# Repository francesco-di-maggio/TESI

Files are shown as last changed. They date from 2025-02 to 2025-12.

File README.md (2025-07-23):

# TESI — TANGIBLE EMBODIED SOUND INTERACTION

<p align="left">
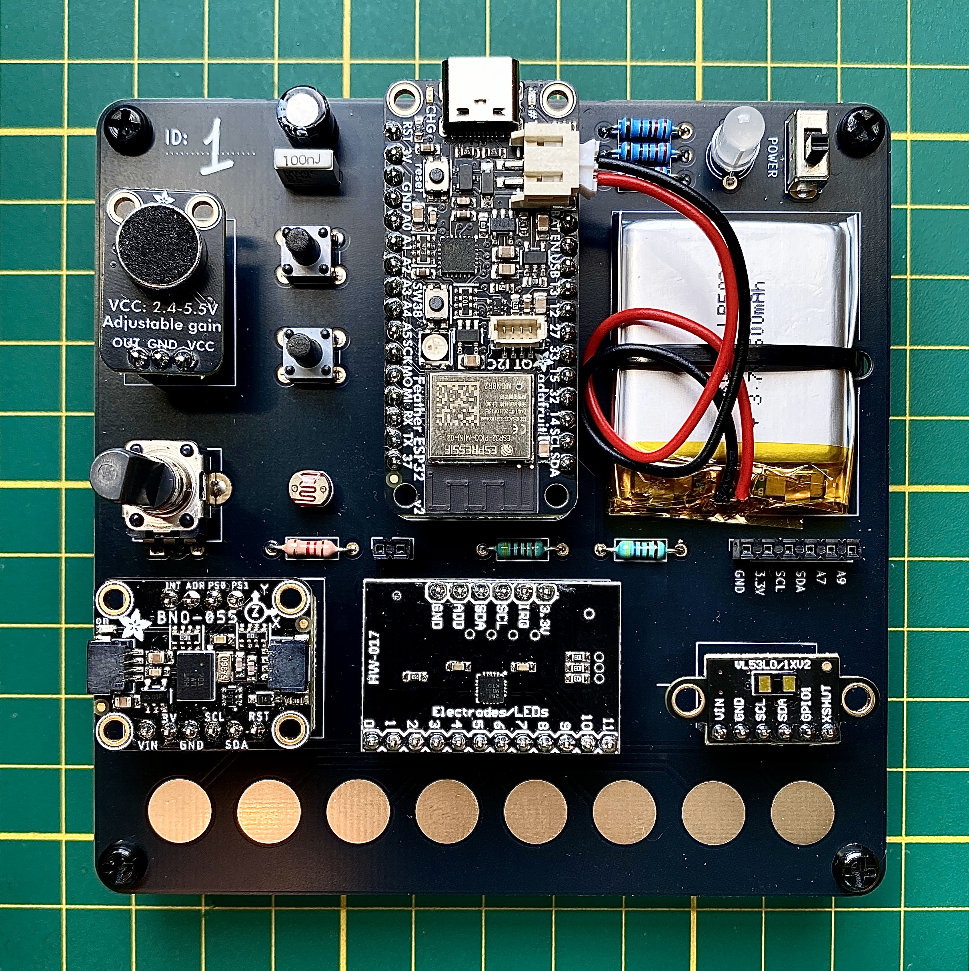
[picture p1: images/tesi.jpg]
TESI
  
</p>

## About
TESI (Tangible Embodied Sound Interaction) is an open-source prototype designed as a sound-centered Tangible User Interface (TUI) for networked, interactive music systems. It enables real-time sensor-based interaction for embodied sound exploration.

TESI is a modular, wireless, and networked interface, leveraging machine learning, decentralized communication, and digital musical instrument (DMI) design. 

### Features
* Wireless and networked using [Adafruit ESP32 Feather V2 - 8MB Flash + 2 MB PSRAM - STEMMA QT](https://www.adafruit.com/product/5400) and [OOCSI](https://oocsi.id.tue.nl/).
* Multi-sensor data collection:
  * Motion (IMU) – BNO055
  * Light – Light-Dependent Resistor (LDR)
  * Distance – Time-of-flight (ToF)
  * Capacitive Touch – MPR121
  * Audio – MAX4466
  * Potentiometer
* Integration with [Max](https://cycling74.com/products/max) via TCP [(Sadam Library)](https://cycling74.com/packages/sadam-library) to process and map data to [Ableton Live](https://www.ableton.com/en/live/).
* Machine learning-based mapping using:
  * FluCoMa
* Custom PCB design (open-source schematics included).

### Repository Contents
* ableton/ – Example Ableton Live set for sound interaction.
* arduino/ – ESP32 firmware for sensor data collection and communication.
* kicad/ – Open-source KiCad schematics and PCB layouts.
* max/ – Max/MSP patches for data processing, mapping, and control.
* oocsi/ - OOCSI local server.

## Setup & Installation
1. Flash the ESP32 with Arduino
  * Install Arduino IDE and ESP32 board support.
  * Upload the firmware in /arduino to ESP32 Feather V2.
2. Set up OOCSI Communication
  * Ensure an OOCSI Server is running.
  * Configure the ESP32 and Max/MSP to connect.
3. Run Max/MSP and Ableton Live
  * Open the Max patches (/max) for data reception and processing.
  * Load the Ableton Live set to explore interactive sound control.

### Dependencies
To work in Max, TESI requires external libraries including:
* (modulo)[https://cycling74.com/packages/modulo]
* (oocsi-max)[https://github.com/francesco-di-maggio/oocsi-max]
* (odot)[https://cycling74.com/packages/odot]
* (Sadam Library)[https://cycling74.com/packages/sadam-library]
* (FluCoMa)[https://www.flucoma.org/]

### Networked Interaction & Distributed Control
TESI operates as part of a system of interconnected objects, using OOCSI for wireless communication between multiple devices. This enables:

* Real-time multi-agent interaction
* Collaborative sound generation
* Adaptive, sensor-driven soundscapes

### Research & Development
TESI is part of my ongoing PhD research at TU Eindhoven, focusing on:

* Tangible and Embodied Interaction
* Modular and Decentralized Ecologies of Smart Objects
* Sound Interaction in TEI and IoT
* Sustainable Interaction Design

## Publications
* Francesco Di Maggio, Bart Hengeveld, and Mathias Funk. 2025. [Making Sense of Decentralized TUIs: A Modular Sound-Centric Approach](https://dl.acm.org/doi/10.1145/3689050.3708332). Proceedings of the Nineteenth International Conference on Tangible, Embedded, and Embodied Interaction. Association for Computing Machinery, New York, NY, USA, Article 136, 1–3. https://doi.org/10.1145/3689050.3708332

### Next Presentation
TESI's first prototype will be presented at (TEI'25)[https://tei.acm.org/2025/] (Tangible, Embedded, and Embodied Interaction) in Bordeaux, France, during a Studio session exploring sustainable, modular, and embodied interaction in sound design., ["Making Sense of Decentralized TUIs: A Modular Sound-Centric Approach"](https://sites.google.com/view/decentralized-sound-tuis/home).

### Contribute & Collaborate
TESI is open-source, and contributions are welcome. You can contribute by:

* Expanding hardware (sensor integration, PCB improvements)
* Enhancing software (Max patches, mappings, sound engines)
* Exploring new applications (live performance, installations, research)
Fork this repository, submit pull requests, or start a discussion in the issues section.

## Credits
### PCB Layout & Schematics
Designed and assembled at TU/e in the [d.search lab](https://research.tue.nl/en/equipments/dsearch-lab) with [Katrien van Riet](https://www.vectorious.nl/) and Geert van den Boomen.

### OOCSI to Plugdata/Max Implementation
Designed at TU/e with [Mathias Funk](https://mathias-funk.com/).

## License
TESI is released under the MIT License, making it free to use, modify, and share.

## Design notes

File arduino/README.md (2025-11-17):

# Arduino Firmware

## Description
ESP32 Feather V2 firmware for multi-sensor data collection and wireless transmission. Reads sensor data, processes it locally, and transmits via OSC, Serial, and OOCSI protocols.

## Hardware Platform
- **MCU**: ESP32 Feather V2
- **Communication**: Wi-Fi 802.11b/g/n
- **Power**: Battery monitoring with voltage divider
- **I/O**: Multiple ADC channels, I2C, GPIO

## Sensor Configuration
The firmware supports the following sensors:

| Sensor | Type | Interface | Purpose |
|---|---|---|---|
| BNO055 | IMU | I2C | Quaternion orientation tracking |
| VL53L1X | ToF Distance | I2C | Proximity detection |
| MPR121 | Capacitive Touch | I2C | 12-channel touch sensing |
| MAX4466 | Microphone | ADC | Environmental sound level |
| LDR | Light Sensor | ADC | Ambient light detection |
| Potentiometer | Analog | ADC | Manual control input |
| Push Button | Digital | GPIO | Discrete input |
| Battery | Voltage | ADC | Power monitoring |

## Project Structure
```
tesi/
├── tesi.ino              # Main Arduino sketch
└── src/
    ├── config.h           # Hardware pin definitions and settings
    ├── config.cpp         # Sensor enable/disable configuration
    ├── secrets.h          # Network credentials (create from template)
    ├── secrets.template.h # Template for network configuration
    ├── sensors.h          # Sensor initialization declarations
    ├── sensors.cpp        # Central sensor management
    ├── stream.h           # Data streaming interface
    ├── stream.cpp         # Main sensor reading loop
    ├── network.h          # Network connectivity interface
    ├── network.cpp        # Wi-Fi and OOCSI implementation
    ├── osc.h              # OSC protocol handling
    ├── osc.cpp            # OSC message formatting and transmission
    ├── ping.h             # Network connectivity monitoring
    ├── ping.cpp           # Ping functionality implementation
    ├── utilities.h        # Shared utility functions
    ├── utilities.cpp      # Serial and OOCSI output functions
    └── [sensor].h/.cpp    # Individual sensor implementations
```

## Configuration
1. **Network Setup**: Copy `secrets.template.h` to `secrets.h` and configure network credentials
2. **Device Identity**: Edit `DEVICE_INDEX` in `config.cpp` to match your physical board number (1, 2, 3, etc.)
3. **OOCSI Protocol**: Uncomment `#define USE_OOCSI` in `config.h` to enable OOCSI communication
4. **Sensor Selection**: Edit `config.cpp` to enable/disable sensors and communication protocols:

### Sensor Configuration Options
Each sensor in `config.cpp` can be configured with the following parameters:
```cpp
SensorConfig SENSOR_NAME = {enabled, osc, serial, oocsi, interval, lastUpdate};
```

| Parameter | Type | Description |
|---|---|---|
| `enabled` | 1/0 | Sensor initialization and data collection |
| `osc` | 1/0 | OSC/UDP message transmission |
| `serial` | 1/0 | Serial port output for debugging |
| `oocsi` | 1/0 | OOCSI protocol transmission |
| `interval` | ms | Update frequency in milliseconds |

### Available Sensors
| Sensor | Variable | Default Interval | Purpose |
|---|---|---|---|
| Battery | `BATTERY` | 5000ms | Power monitoring |
| Light Sensor | `LDR` | 20ms | Ambient light detection |
| Microphone | `MIC` | 30ms | Environmental sound level |
| Potentiometer | `POT` | 10ms | Manual control input |
| Distance | `DISTANCE` | 20ms | VL53L1X proximity detection |
| Quaternion | `QUAT` | 30ms | BNO055 orientation tracking |
| Push Button | `PUSH` | 5ms | Discrete input |
| Capacitive Touch | `CAP` | 5ms | MPR121 touch sensing |
| Heartbeat Ping | `PING` | 1000ms | Device alive status monitoring |

5. **Update Rates**: Adjust sensor polling intervals in individual sensor configurations

### Important Configuration Notes
- **Device Index**: Each board must have a unique `DEVICE_INDEX` value in `config.cpp` for proper identification
- **OOCSI Enable**: Uncomment `// #define USE_OOCSI` in `config.h` to activate OOCSI protocol functionality

## Network Protocols
- **OSC**: Open Sound Control over UDP for real-time applications
- **Serial**: Direct UART output for debugging and local monitoring  
- **OOCSI**: Distributed messaging protocol for multi-device coordination

## Compilation Requirements
- **Arduino IDE**: Version 2.0 or later
- **ESP32 Board Package**: Version 3.1.2 (Espressif Systems ESP32 boards)
- **Libraries**:
  - Adafruit BNO055
  - Adafruit VL53L1X
  - Adafruit MPR121 (version 1.1.3)
  - WiFi (ESP32 core)
  - WiFiUdp (ESP32 core)
  - OOCSI

## Sensor Architecture
Each sensor follows a consistent three-function pattern:
- `init[Sensor]()`: Hardware initialization and configuration
- `read[Sensor]()`: Data acquisition and local processing
- `send[Sensor]()`: Conditional transmission based on change thresholds

## Data Processing
- **Filtering**: Exponential moving average (EMA) and noise reduction
- **Thresholding**: Change detection to minimize redundant transmissions
- **Scaling**: Sensor-specific calibration and range mapping

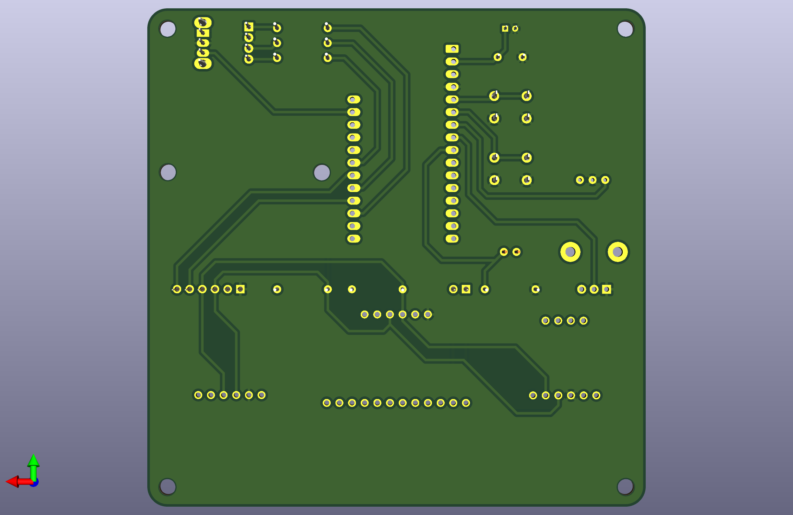
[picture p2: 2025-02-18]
kicad/tesi/tesi-pictures/tesi-pcb-b.png

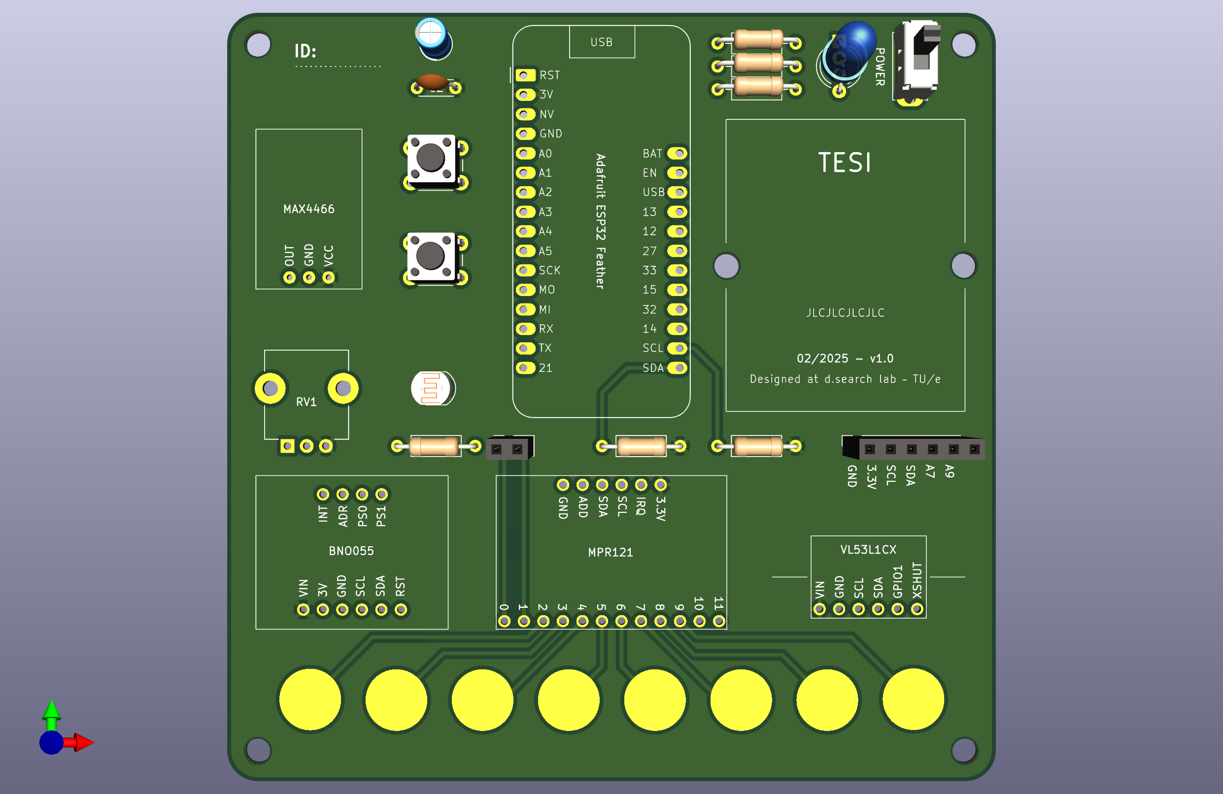
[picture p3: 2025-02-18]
kicad/tesi/tesi-pictures/tesi-pcb-a.png

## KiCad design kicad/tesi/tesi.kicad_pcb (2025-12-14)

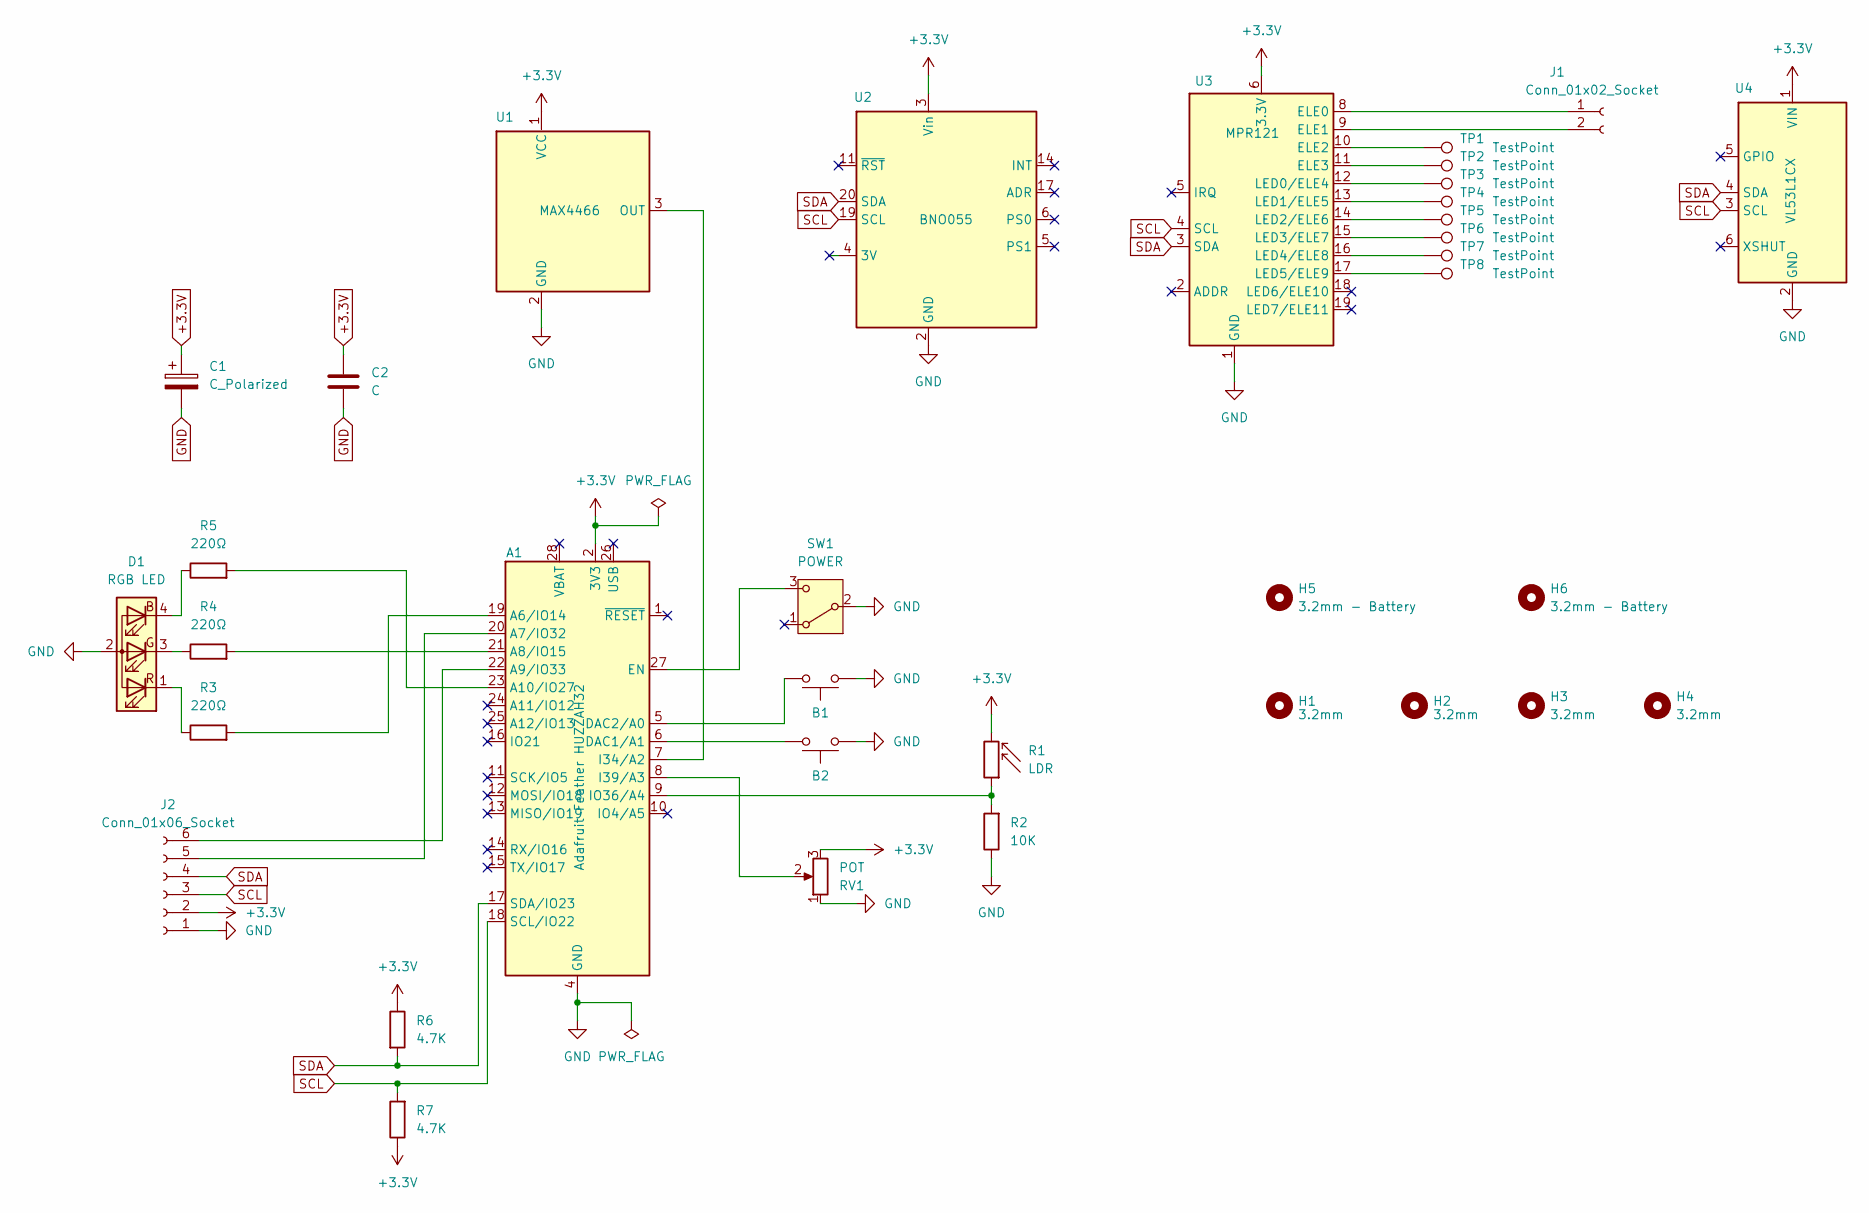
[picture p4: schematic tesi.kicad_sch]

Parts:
A1: Adafruit Feather HUZZAH32; Adafruit ESP32 Feather
B1, B2: SW_PUSH_6mm
C1: C_Polarized; CP_Radial_D4.0mm_P2.00mm
C2: C; C_Disc_D4.3mm_W1.9mm_P5.00mm
D1: RGB LED; LED_D5.0mm-4_RGB_Wide_Pins
H1, H2, H3, H4: 3.2mm; MountingHole_3.2mm_M3
H5, H6: 3.2mm - Battery; MountingHole_3.2mm_M3
J1: Conn_01x02_Socket; PinSocket_1x02_P2.54mm_Vertical
J2: Conn_01x06_Socket; PinSocket_1x06_P2.54mm_Vertical
R1: LDR; R_LDR_4.9x4.2mm_P2.54mm_Vertical
R2: 10K; R_Axial_DIN0207_L6.3mm_D2.5mm_P10.16mm_Horizontal
R3, R4, R5: 220Ω; R_Axial_DIN0207_L6.3mm_D2.5mm_P10.16mm_Horizontal
R6, R7: 4.7K; R_Axial_DIN0207_L6.3mm_D2.5mm_P10.16mm_Horizontal
RV1: POT; Potentiometer_TT_P0915N
SW1: POWER; Switch
TP1, TP2, TP3, TP4, TP5, TP6, TP7, TP8: TestPoint; TouchPad - 4.0mm
U1: MAX4466
U2: BNO055
U3: MPR121
U4: VL53L1CX; VL53L1X

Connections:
+3.3V: A1.2 (3V3), C1.1, C2.1, J2.2, R1.2, R6.1, R7.1, RV1.3, U1.1 (VCC), U2.3 (Vin), U3.6 (3.3V), U4.1 (VIN)
GND: A1.4 (GND), B1.1, B2.1, C1.2, C2.2, D1.2 (A), J2.1, R2.1, RV1.1, SW1.2 (B), U1.2 (GND), U2.2 (GND), U3.1 (GND), U4.2 (GND)
unnamed: A1.19 (A6/IO14), R3.2
unnamed: A1.20 (A7/IO32), J2.5
unnamed: A1.21 (A8/IO15), R4.2
unnamed: A1.22 (A9/IO33), J2.6
unnamed: A1.23 (A10/IO27), R5.2
unnamed: A1.6 (DAC1/A1), B2.2
unnamed: A1.5 (DAC2/A0), B1.2
unnamed: A1.27 (EN), SW1.3 (C)
unnamed: A1.7 (I34/A2), U1.3 (OUT)
unnamed: A1.8 (I39/A3), RV1.2
unnamed: A1.9 (IO36/A4), R1.1, R2.2
unnamed: D1.4 (BK), R5.1
unnamed: D1.3 (GK), R4.1
unnamed: D1.1 (RK), R3.1
unnamed: J1.1, U3.8 (ELE0)
unnamed: J1.2, U3.9 (ELE1)
unnamed: TP1.1, U3.10 (ELE2)
unnamed: TP2.1, U3.11 (ELE3)
unnamed: TP3.1, U3.12 (LED0/ELE4)
unnamed: TP4.1, U3.13 (LED1/ELE5)
unnamed: TP5.1, U3.14 (LED2/ELE6)
unnamed: TP6.1, U3.15 (LED3/ELE7)
unnamed: TP7.1, U3.16 (LED4/ELE8)
unnamed: TP8.1, U3.17 (LED5/ELE9)
SCL: A1.18 (SCL/IO22), J2.3, R7.2, U2.19 (SCL), U3.4 (SCL), U4.3 (SCL)
SDA: A1.17 (SDA/IO23), J2.4, R6.2, U2.20 (SDA), U3.3 (SDA), U4.4 (SDA)

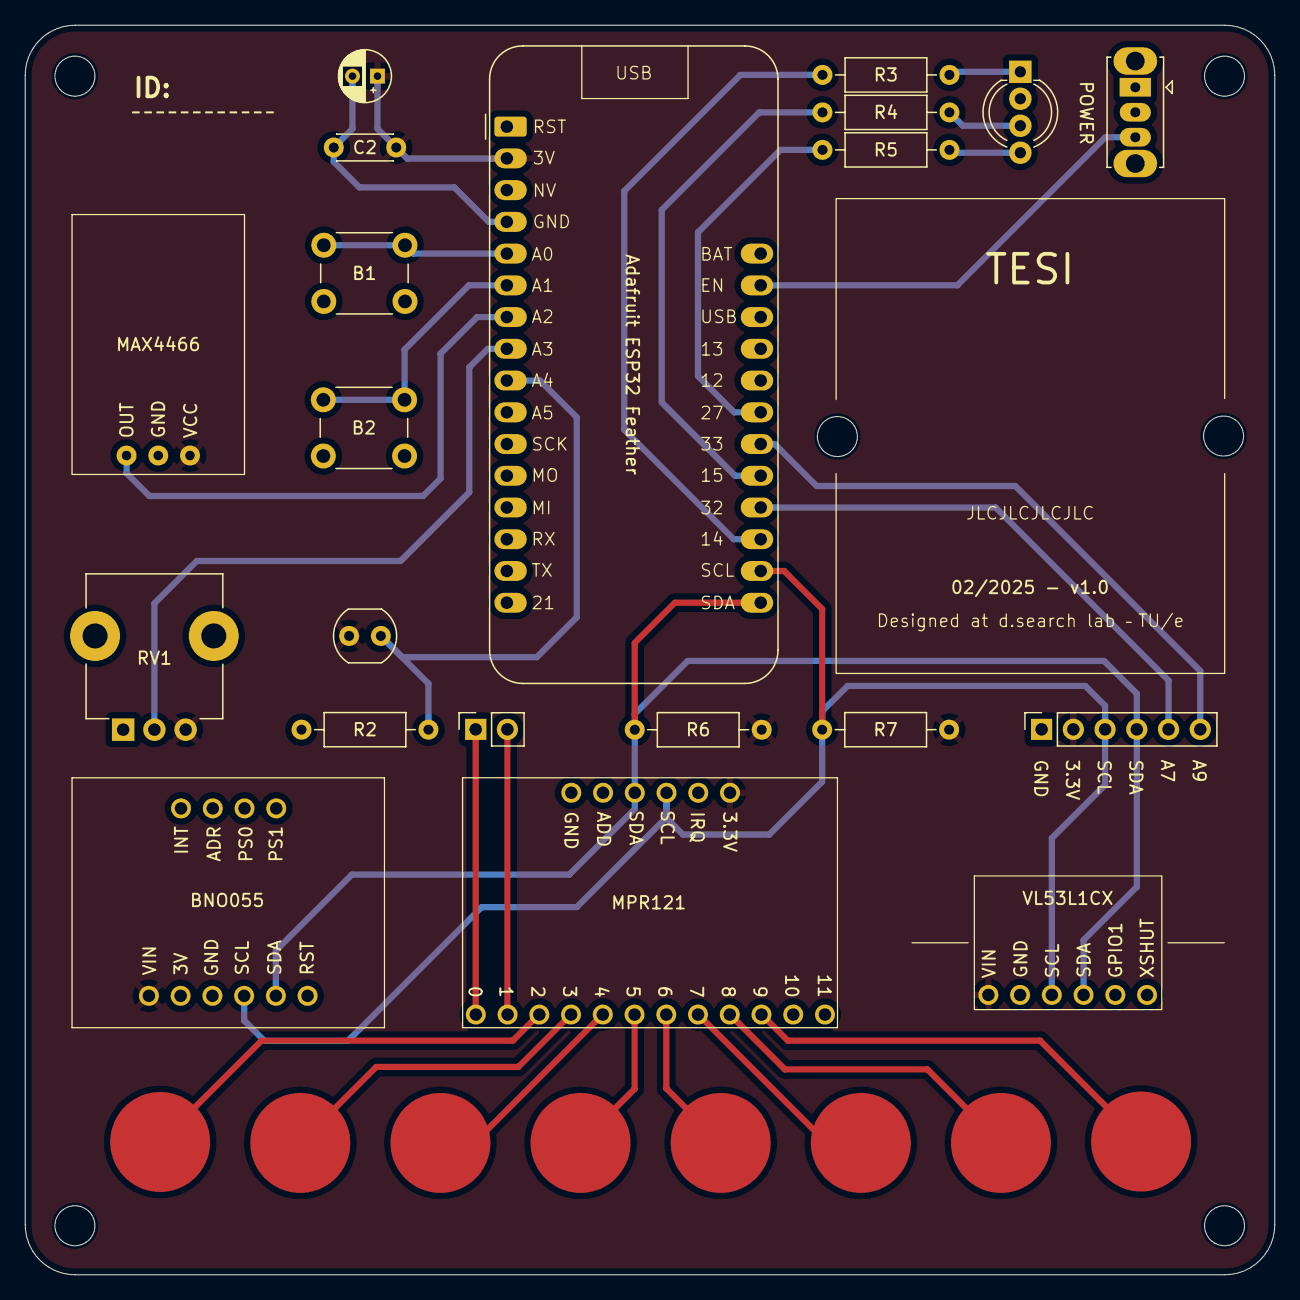
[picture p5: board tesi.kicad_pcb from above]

Board: 2 copper layers, 100.0 x 100.0 mm, 35 parts (0 on the bottom side), 28 nets.

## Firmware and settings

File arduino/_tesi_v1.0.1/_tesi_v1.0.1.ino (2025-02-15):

/* -------------------------------------------------------------------------
     TESI
     
   © 2025 Francesco Di Maggio
     Modified: 20-01-2025
   
    - Connect ESP32 Huzzah32 Feather Board to WiFi
    1. Read MPR121 buttons 1 to 6
    2. Read LDR on A0
    3. Read BNO055 on I2C
    4. Read KY-038 mic level
    5. Read VL53L4CX distance
    - Send each value as a separate OSC message
------------------------------------------------------------------------ */

#include <Wire.h>
#include <Adafruit_Sensor.h>
#include <Adafruit_BNO055.h>
#include <utility/imumaths.h>
#include <Adafruit_MPR121.h>
#include <vl53l4cx_class.h>

#include <WiFi.h>
#include <WiFiUdp.h>
#include <OSCMessage.h>

// -------------------------------------------------------------------------
// WiFi & OSC Configurations
// -------------------------------------------------------------------------

// const char* ssid = "VRV951743477E";      // Network SSID
// const char* pass = "43210Sijm";          // Network password

const char* ssid = "iotroam";            // Network SSID
const char* pass = "esp-tei25";          // Network password

WiFiUDP Udp;                             // UDP instance for OSC communication

// const IPAddress outIp(192, 168, 2, 135); // Remote IP of your computer
const IPAddress outIp(145, 116, 45, 125); // Remote IP of your computer

const unsigned int outPort = 8000;       // Remote port to receive OSC
// const unsigned int localPort = 9000;     // Local port to listen for OSC packets (actually not used for sending)

// -------------------------------------------------------------------------
// BATTERY
#define BATTERY_PIN 35  // GPIO35 (A13) is internally connected to VBAT

// ADC parameters
#define ADC_MAX 4095.0  // ESP32 uses a 12-bit ADC (0-4095)
#define REF_VOLTAGE 3.3  // ESP32 ADC reference voltage (regulated 3.3V)
#define VOLTAGE_DIVIDER_RATIO 2.0  // Internal voltage divider halves the battery voltage

// Battery voltage range
#define BATTERY_FULL 4.2  // Voltage at 100%
#define BATTERY_EMPTY 3.2  // Voltage at 0%

// -------------------------------------------------------------------------
// BNO055
// Adafruit_BNO055 bno = Adafruit_BNO055(55, 0x28, &Wire);
Adafruit_BNO055 bno = Adafruit_BNO055(55, 0x28);

// -------------------------------------------------------------------------
// LDR
const int ldrPin = A4; // Connect LDR to pin (with appropriate resistor divider)

// Global variable to track the minimum and maximum values
int ldrMin = 40; // Minimum distance threshold
int ldrMax = 0;  // Start with a small default value to avoid division by zero
float ldr = 0.0;
const float ldrSmooth = 0.4;  // Adjust smoothing factor (0.0 - 1.0, lower = smoother)

// -------------------------------------------------------------------------
// MIC KY-038
const int micPin = A3;

// Fixed min/max calibration values
const int micMin = 100;
const int micMax = 180;

// Smoothing factor (0.0 = no smoothing, 1.0 = maximum smoothing)
const float micSmooth = 0.4;  // Set this to 0.1 for high smoothing, 0.9 for low smoothing

// Variable to store the smoothed value
float mic = 0.0;

// Variable sampling rate to determine min and max
const int samples = 50; // Samples per second (adjust as needed)

// -------------------------------------------------------------------------
// MPR121
Adafruit_MPR121 cap = Adafruit_MPR121(); // MPR121 touch sensor instance
// const uint8_t MPR121_ADDR = 0x5A;        // Default I2C address for MPR121
const int BUTTON_COUNT = 8;              // Buttons 1 to 8

int lastTouched = 0;   // Previous MPR121 touch state
int currTouched = 0;   // Current MPR121 touch state

// -------------------------------------------------------------------------
// POT
const int potPin = A2;

// Variable to store the smoothed value
float pot = 0.0;
const int potMin = 0;    // Minimum raw reading (adjust if needed)
const int potMax = 4095; // Maximum raw reading for ESP32 (12-bit ADC)

// -------------------------------------------------------------------------
// PUSH
const int pushPin = 25;

// -------------------------------------------------------------------------
// RGB LED
const int redPin = 15;    // Red LED pin
const int greenPin = 33;  // Green LED pin
const int bluePin = 27;    // Blue LED pin

// Uncomment this line if using a Common Anode LED
#define COMMON_ANODE

// -------------------------------------------------------------------------
// VL53L4CX
VL53L4CX sensor(&Wire, -1);  // Initialize without XSHUT pin

// Smoothing factor (0.0 = no smoothing, 1.0 = maximum smoothing)
const float distanceSmooth = 0.6;  // Set this to 0.1 for high smoothing, 0.9 for low smoothing

// Variable to store the smoothed value
float distance = 0.0;

// Global variable to track the minimum and maximum distance values
int distanceMin = 20; // Minimum distance threshold
int distanceMax = 0;  // Start with a small default value to avoid division by zero

// Timing Variables
unsigned long lastBNOTime = 0, lastButtonTime = 0, lastLDRTime = 0;
unsigned long lastMICTime = 0, lastDistanceTime = 0, lastBatteryTime = 0;

// -------------------------------------------------------------------------
// SETUP 
// -------------------------------------------------------------------------

void setup() {
  // Start Serial communication
  Serial.begin(115200);

  // Set PUSH pin
  pinMode(pushPin, INPUT_PULLUP);

  // Set up RGB LED pins
  pinMode(redPin, OUTPUT);
  pinMode(greenPin, OUTPUT);
  pinMode(bluePin, OUTPUT);

  // Red light on startup
  setColor(255, 0, 0); 
  delay(100);
  
  // analogReadResolution(12);  // Set ESP32 ADC resolution to 12-bit (0-4095)
  // analogSetAttenuation(ADC_11db);  // Full 0-3.3V range  
  
  // while (!Serial) delay(10);  // wait for serial port to open!

  // Initialize I2C communication
  Wire.begin(); 

  // Connect to WiFi
  Serial.print("Connecting to ");
  Serial.println(ssid);

  WiFi.begin(ssid, pass);

  while (WiFi.status() != WL_CONNECTED) {
    delay(100);
    Serial.print(".");
  }
  Serial.println("\nWiFi connected!");
  // Serial.print("IP address: ");
  // Serial.println(WiFi.localIP());

  // Start UDP
    // Udp.begin(localPort);
    // Serial.print("UDP local port: ");
    // Serial.println(localPort);
  
  // Set power-saving settings  
  esp_wifi_set_ps(WIFI_PS_MIN_MODEM);
  esp_wifi_set_max_tx_power(50);
  WiFi.setSleep(true); // Enable sleep mode  

  // Initialize BNO055
  if (!bno.begin()) {
    Serial.println("No BNO055 detected. Check wiring or I2C ADDR!");
    while (1) { delay(10); } // Halt execution if BNO055 is not detected
  }
  Serial.println("BNO055 initialized!"); 

  // Use external crystal for better accuracy
  bno.setExtCrystalUse(true);

// Initialize MPR121
  if (!cap.begin(0x5A)) {
    Serial.println("No MPR121 detected. Check wiring or I2C ADDR!");
    while (1) { delay(10); } // Halt execution if MPR121 is not detected
  }
  Serial.println("MPR121 initialized!"); 

  if (sensor.begin() != 0) {
    Serial.println("No VL53L4CX detected. Check wiring or I2C ADDR!");
    while (1) { delay(10); }
  }
  Serial.println("VL53L4CX initialized!"); 

  sensor.InitSensor(0x10);  // Default I2C address
  sensor.VL53L4CX_StartMeasurement();  

  calibrateMaxDistance(); // Perform initial calibration at startup
  calibrateMaxLDR();      // Perform initial LDR calibration at startup

  // Green light
  setColor(0, 255, 0); 
  delay(500);

  // RGB off  
  setColor(0, 0, 0);
}

// -------------------------------------------------------------------------
// LOOP
// -------------------------------------------------------------------------

// void loop() {
//   // readAccelAndSendOSC();    // Read and send accelerometer data
//   readQuatAndSendOSC();     // Read and send quaternions
//   readLDRAndSendOSC();      // Read and send LDR value
//   readMICAndSendOSC();      // Read and send mic level
//   readButtonsAndSendOSC();  // Read and send button states
//   readPushAndSendOSC();     // Read and send push state
//   readDistanceAndSendOSC(); // Read and send distance value
//   readPOTAndSendOSC();      // Read and send potentiometer value
//   readBatteryAndSendOSC();  // Call function to print battery voltage & percentage
  
//   // Adjust sampling rate if necessary
//   delay(5); 
// }

void loop() {
  unsigned long currentMillis = millis();

  if (currentMillis - lastBNOTime >= 20) {  
      readQuatAndSendOSC();
      lastBNOTime = currentMillis;
  }

  if (currentMillis - lastButtonTime >= 5) {  
      readButtonsAndSendOSC();
      readPushAndSendOSC();
      lastButtonTime = currentMillis;
  }

  if (currentMillis - lastLDRTime >= 10) {  
      readLDRAndSendOSC();
      lastLDRTime = currentMillis;
  }

  if (currentMillis - lastMICTime >= 10) {  
      readMICAndSendOSC();
      lastMICTime = currentMillis;
  }

  if (currentMillis - lastDistanceTime >= 10) {  
      readDistanceAndSendOSC();
      lastDistanceTime = currentMillis;
  }

  if (currentMillis - lastBatteryTime >= 5000) {  
      readBatteryAndSendOSC();
      lastBatteryTime = currentMillis;
  }
}

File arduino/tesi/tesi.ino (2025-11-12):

/* -------------------------------------------------------------------------
    TESI (Tangible and Embodied Sound Interaction)
     
    ©2025 Francesco Di Maggio
    Modified: 20-09-2025
   
    - Designed for Adafruit HUZZAH32 Feather / ESP32 Feather V2
    - Using WiFi (ADC#2 won't work!)
    - Read BNO055 (motion) on I2C
    - Read MPR121 (capacitive touch pads) on I2C
    - Read VL53L1X (distance: 50-4000mm) on I2C
    - Read LDR (light) on pin 4
    - Read MAX4466 (mic level) on pin 3
    - Read POT on pin 2
    - Read PUSH1 on pin 26
    - Read PUSH2 on pin 25
    - Write RGB Led on pins 14, 15, 27
    - Send sensor data via OSC/UDP, OOCSI, or Serial
    - Remote OSC configuration with hybrid addressing:
      * Generic:       /tesi/config/* → direct IP (e.g., 192.168.8.100:9001)
      * Specific:    /tesi/2/config/* → specific device (e.g., 192.168.8.101:9001)
      * Broadcast: /tesi/all/config/* → all devices (subnet broadcast 192.168.8.255:9001)
    - Configurable settings in secrets.h
    - Flash memory persistence for IP settings
------------------------------------------------------------------------ */

#include "src/config.h"
#include "src/utilities.h"
#include "src/network.h"
#include "src/sensors.h"
#include "src/stream.h"
#include "src/osc.h"

// -------------------------------------------------------------------------
// SETUP 
// -------------------------------------------------------------------------
void setup() {
  Serial.begin(115200);
  delay(1000);
  
  Serial.println();
  Serial.println(F("══════════════════════"));
  Serial.println();
  Serial.println(F("Initializing system..."));
  Serial.println();
  Serial.print(F("> TESI "));
  Serial.println(DEVICE_INDEX);
  Serial.println();

  pinMode(PUSH1_PIN, INPUT_PULLUP);
  pinMode(PUSH2_PIN, INPUT_PULLUP);
  pinMode(RED_PIN, OUTPUT);
  pinMode(GREEN_PIN, OUTPUT);
  pinMode(BLUE_PIN, OUTPUT); 

  setColor(255, 0, 0); // RED LIGHT: Booting

  printMacAddress();

  setupWiFi();

  #if defined(USE_OOCSI) // Change this in config.h
  setupOOCSI();
  #endif

  setupOSC();

  setupSensors();

  Serial.print(F("> TESI "));
  Serial.println(DEVICE_INDEX);
  Serial.println();
  Serial.println(F("System initialization complete!"));
  Serial.println(); 
  Serial.println(F("═══════════════════════════════"));
  Serial.println();

  setColor(0, 255, 0); delay(500); setColor(0, 0, 0); // GREEN LIGHT: Ready, then off
}

// -------------------------------------------------------------------------
// LOOP
// -------------------------------------------------------------------------
void loop() {
  listenOSC();

  unsigned long now = millis();
  streamSensors(now);

  delay(1);
}

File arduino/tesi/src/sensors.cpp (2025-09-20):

#include "sensors.h"

// -------------------------------------------------------------------------
// Sensor Instances (only defined here!)
// -------------------------------------------------------------------------
Adafruit_BNO055 BNO_SENSOR = Adafruit_BNO055(55, 0x28, &Wire);
Adafruit_VL53L1X VL53_SENSOR = Adafruit_VL53L1X();
Adafruit_MPR121 CAP_SENSOR = Adafruit_MPR121();

// -------------------------------------------------------------------------
// Initialize All Sensors
// -------------------------------------------------------------------------
void setupSensors() {
    Serial.println(F("3. Initializing sensors..."));
    Serial.println();
    Wire.begin();  // Start I2C communication

    initPOT();
    initLDR();
    initMPR121();
    initVL53L1X();
    initBNO055();
    
    Serial.println();
    Serial.println(F("Sensors initialized successfully!"));
    Serial.println();
}

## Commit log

2025-02-06 add KiCad files
    [tesi.kicad_pcb, tesi.kicad_sch]
2025-02-11 update pcb
    [tesi.kicad_pcb, tesi.kicad_sch]
2025-09-20 Implement hybrid OSC addressing system with memory optimizations
    - Add three OSC addressing methods: explicit (/INDEX/), generic (/tesi/), and broadcast (/all/)
    - Optimize memory usage with single buffer for address parsing
    - Implement configurable IN_PORT (9001) and OUT_PORT (8001) via secrets.h
    - Add unified DEBUG flag system for consistent debug control
    - Update documentation with simplified startup messages
    - Add complete /all functionality including IP configuration
    - Improve error handling and code organization
    [VL53L1X.cpp, network.cpp, osc.cpp]
2025-09-20 Improve boot sequence with clean, professional serial monitor messages
    - Add structured boot sequence with numbered steps (1. WiFi, 2. OSC, 3. Sensors)
    - Clean header with project title and device index
    - WiFi section shows target IP/port where messages are sent
    - OSC section shows local IP/port where device listens
    - Individual sensor status messages (MPR121, VL53L1X, BNO055 > OK)
    - Professional formatting with proper spacing and visual hierarchy
    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
2025-09-21 Optimize sensor timing and OSC performance for musical applications
    - Improve sensor sampling rates for musical timing:
    * PUSH/CAP sensors: 10ms → 5ms (200Hz for musical responsiveness)
    * POT sensor: 20ms → 10ms (100Hz for smooth control)
    * MIC sensor: 40ms → 30ms (33Hz optimized)
    * BATTERY sensor: 4s → 5s (reduced polling frequency)
    - Optimize OSC message handling for performance:
    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
2025-10-27 update for submission
    [tesi-B_Cu.gbl, tesi-B_Mask.gbs, tesi-B_Paste.gbp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]
2026-10-16 Documentation site in site/ (Astro, served at francescodimaggio.nl/tesi/), deployed by GitHub Actions. README: layers, versions, site link, current publications
2026-10-16 Headings in Title Case, as the family rule
